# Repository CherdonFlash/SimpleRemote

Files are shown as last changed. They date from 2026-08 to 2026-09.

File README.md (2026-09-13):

# SimpleRemote

## 项目介绍

SimpleRemote 是基于 STM32F103C6T6A 设计的一款小型无线遥控器，集成双摇杆、四个按键、拨动开关、OLED 屏幕和锂电池充电电路。遥控器通过 NRF24L01 发送摇杆、按键、开关和电池电压数据，通过 CW2015CHBD 获取电池电量并显示在屏幕上。

尽量保持代码模块化，并为主要逻辑添加中文注释，方便理解和二次开发。屏幕界面由我结合 AI 辅助和手写绘图函数实现。

- Git项目仓库：[CherdonFlash/SimpleRemote](https://github.com/CherdonFlash/SimpleRemote)
- 联系 QQ：1228879785

## 项目图片

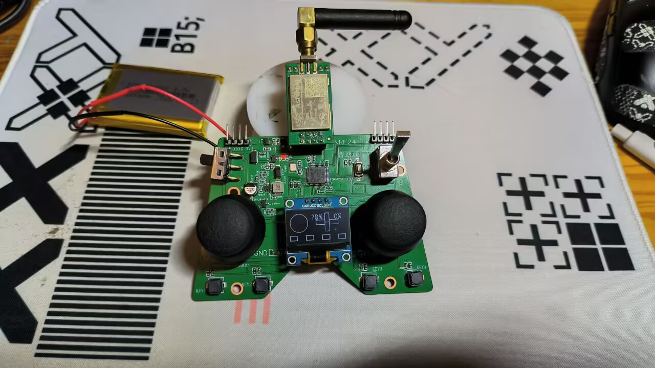
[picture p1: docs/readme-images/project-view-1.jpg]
项目图片 1


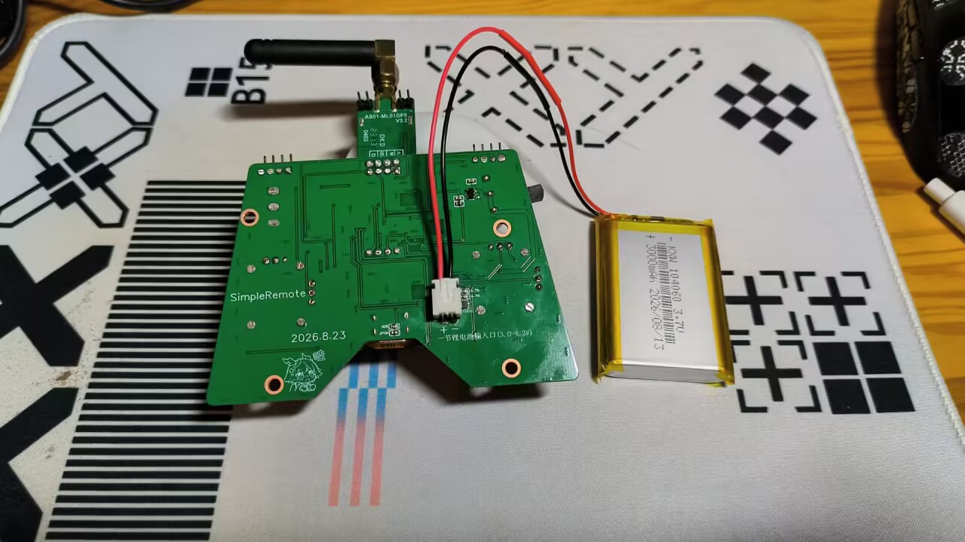
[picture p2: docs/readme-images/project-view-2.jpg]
项目图片 2


## 功能架构

```mermaid
flowchart TB
    subgraph IN["输入采集"]
        J1["双轴摇杆 ×2<br/>ADC1 + DMA（PA2/PA3/PA4/PB0）"]
        K1["按键 ×4<br/>TIM2 中断扫描（PB12～PB15）"]
        S1["拨动开关<br/>GPIO 读取（PA8）"]
    end

    subgraph BAT["电池与电量监测"]
        B0["1S 锂电池<br/>3000 mAh · 内置保护板"]
        B1["CW2015CHBD 电量计<br/>电池电压 · SOC<br/>软件 I2C（PB10/PB11）"]
        B0 --> B1
    end

    P1["STM32F103C6T6A · 72 MHz<br/>输入处理 · 数据组包 · 显示更新"]

    subgraph OUT["输出"]
        D1["0.96 英寸 OLED<br/>I2C1 + DMA（PB6/PB7）"]
        R1["NRF24L01 无线发送<br/>SPI1 · 32 字节数据帧"]
        U1["USART1 调试输出<br/>115200 · 8N1"]
    end

    J1 --> P1
    K1 --> P1
    S1 --> P1
    B1 --> P1
    P1 --> D1
    P1 --> R1
    P1 --> U1
    P1 -. 周期喂狗 .-> W["独立看门狗 IWDG"]
```

## 主要功能

| 模块 | 功能 | 主要源码 |
| --- | --- | --- |
| 双摇杆 | ADC1 四通道连续采样，DMA 循环搬运，映射为四路有符号控制量 | [mobile.c](mcu/Code/mobile.c) |
| 按键 | 四个按键周期扫描、消抖，非阻塞状态机识别单击、双击和长按 | [key.c](mcu/Code/key.c) |
| 拨动开关 | 读取开关档位，参与显示和无线组包 | [turn.c](mcu/Code/turn.c) |
| OLED | 128×64 帧缓冲绘图，硬件 I2C＋DMA 全屏刷新，显示摇杆、按键、开关和电量状态 | [app_display.c](mcu/Code/app_display.c)、[oled096.c](mcu/Code/oled096.c)、[iic.c](mcu/Code/iic.c) |
| 无线发送 | 硬件 SPI1 驱动 NRF24L01，发送 32 字节控制数据，启用自动应答和自动重发 | [nrf24.c](mcu/Code/nrf24.c) |
| 电量监测 | PB10/PB11 开漏 GPIO 模拟 I2C，每秒读取电池数据，更新屏幕电量百分比 | [cw2015.c](mcu/Code/cw2015.c)、[bat.c](mcu/Code/bat.c) |
| 串口 | USART1 输出初始化信息和发送数据；支持格式化输出，采用阻塞发送 | [uart.c](mcu/Code/uart.c) |
| 看门狗 | 主循环定期喂独立看门狗，异常时自动复位 | [main.c](mcu/User/main.c) |

### 无线数据帧

无线载荷固定为 32 字节，组包逻辑位于 [NRF_SendAll()](mcu/Code/nrf24.c)。

| 字节偏移（从 0 开始） | 内容 | 编码 |
| --- | --- | --- |
| 0 | 帧头 | `0x51` |
| 1～4 | 四路摇杆控制量 | 每路 `int8_t`，范围 −128～127，以 8 位补码传输 |
| 5 | 四个按键的按住状态 | bit0～bit3 对应按键 1～4，1 表示按住；bit4～bit7 为 0 |
| 6 | 拨动开关 | `turn_get()` 返回的 0/1 |
| 7～8 | 电池电压 | 单位 mV，7 为高字节，8 为低字节 |
| 9～30 | 预留 | 0 |
| 31 | 帧尾 | `0x15` |

按键字段使用消抖后的持续按住状态。无线芯片启用 2 字节 CRC，帧头和帧尾用于标识业务数据格式。

## 主控与主要元器件

主控采用 STM32F103C6T6A，Cortex-M3 内核，外部 8 MHz 晶振经 PLL 倍频至 72 MHz。程序采用裸机主循环，使用 STM32F10x 标准外设库 V3.5.0，Keil 工程按 32 KB Flash、10 KB RAM 配置。

STM32F103C6 具有一路硬件 I2C 和一路 SPI：OLED 使用 I2C1，无线模块使用 SPI1，电量计使用独立的软件 I2C。器件资料见 [ST 官方页面](https://www.st.com/en/microcontrollers-microprocessors/stm32f103c6.html)。

| 元器件 | 用途 |
| --- | --- |
| STM32F103C6T6A | 输入采集、显示和无线通信主控 |
| E01-ML01DP5 | 基于 NRF24L01+ 的 2.4 GHz PA 无线模块 |
| 0.96 英寸 OLED | 128×64 SSD1306 显示模组，四针 I2C 接口 |
| 3D161 摇杆 ×2 | 提供四路模拟控制量 |
| K2-1817UQ-C4SW-01 ×4 | 轻触按键输入 |
| CW2015CHBD | 单节锂电池电压与电量监测 |
| IP2312U | USB-C 输入的单节锂电池充电 |
| FP6291LR-G12 | 电池升压供电 |
| RT9013-33GB-MS ×2 | 分别产生主系统 3V3 和无线模块 NRF24_3V3 |
| 8 MHz 晶振 | MCU 外部高速时钟源 |

## 接口定义

| 功能 | STM32 引脚 |
| --- | --- |
| 摇杆 ADC | PA2、PA3、PA4、PB0 |
| 电量计软件 I2C | PB10/SCL、PB11/SDA |
| 按键 1～4 | PB12～PB15，外部上拉，低电平按下 |
| 拨动开关 | PA8 |
| OLED I2C1 | PB6/SCL、PB7/SDA |
| NRF24L01 SPI1 | PA5/SCK、PA6/MISO、PA7/MOSI |
| NRF24L01 控制 | PB8/CE、PB9/CSN、PA15/IRQ |
| USART1 | PA9/TX、PA10/RX，115200 baud、8N1 |

## 性能、功耗与续航

以下整理了我的电流测量记录、固件运行统计和理论估算。估算使用 3000 mAh 标称容量，并假设记录的电流为电池端整机平均电流；实际续航受电池容量、温度、老化和工作状态影响。

### 电池与功耗

| 项目 | 参数 / 数据 | 说明 |
| --- | --- | --- |
| 电池 | 1S 聚合物软包锂电池，3000 mAh | 内置保护板，支持 3 A 充电 |
| 关机静态电流 | **32.7 μA** | 实测整机关机电流 |
| 开机运行电流 | **54 mA** | 实测运行电流，随供电电压和工作状态变化 |
| 关机耗电量 | 约 0.785 mAh/天、23.54 mAh/30 天 | 按 32.7 μA 计算，不含自放电 |

### 无线、屏幕与按键

| 项目 | 参数 / 数据 | 说明 |
| --- | --- | --- |
| 无线射频中心频率 | **2.400 GHz** | RF_CH＝0 |
| 无线空中数据速率 | **2 Mbps** | 射频配置值 |
| SPI1 时钟 | **9 MHz** | 72 MHz 八分频 |
| OLED I2C 时钟 | **400 kHz** | 硬件 I2C1，已通过 60.104 s 软件稳定性测试 |
| OLED 完整刷新率 | **约 19.65 FPS** | 400 kHz、关闭逐包日志，60.104 s 完成 1181 帧 |
| 按键扫描周期 | **10 ms** | TIM2 定时扫描，100 Hz |
| 按键消抖响应时间 | **约 10～20 ms** | 从输入稳定到软件确认的代码推算，不含机械抖动和硬件 RC 延迟 |
| 长按判定时间 | **500 ms** | 按键状态机计时参数 |
| 双击等待窗口 | **400 ms** | 按键状态机计时参数 |
| 电量计采集周期 | **1000 ms** | 首次立即读取，之后每秒更新 |

OLED 刷新率统计于 2026-09-13：历史基线为 300 kHz 总线且保留逐包串口日志，约 14.09 FPS；本次关闭逐包日志并将 I2C 提升到 400 kHz，60.104 s 完成 1181 帧，约 19.65 FPS。该数值表示完整帧传输完成速率，会随主循环负载变化。详细测试结果见[固件优化与调试记录](mcu/固件优化与调试记录_2026-09-13.md)，测量脚本为 [Measure-Runtime.ps1](scripts/firmware/Measure-Runtime.ps1)。

### 充电与续航估算

| 项目 | 估算结果 | 计算依据 |
| --- | --- | --- |
| 充电电流设定 | **约 2.65 A** | IP2312U 的 ICHG 电阻为 51 kΩ，135000/51000≈2.647 A，属于名义设定值 |
| 标称容量÷设定充电电流 | 约 1.13 小时（68 分钟） | 3000 mAh÷2647 mA，仅为全程恒流假设下的容量换算 |
| 满电持续开机续航 | **约 55.6 小时（2.31 天）** | 3000 mAh÷54 mA |
| 满电关机、仅静态负载耗尽容量 | 约 3823 天（10.47 年） | 3000 mAh÷0.0327 mA，忽略自放电、老化及低压截止损失 |
| 每天开机 1 小时、关机 23 小时 | 约 54.8 天 | 每日耗电约 54＋0.0327×23＝54.75 mAh |

充电采用恒流/恒压过程，**68 分钟不是实际充满时间**；恒压收尾、输入限流和温度都会影响充电时长。**10.47 年也不是安全存放或补电周期**，不能用它判断电池何时严重过放。上述时间均为估算，不能代替完整充放电及长期存放测量。

充电参数依据[原理图网表](hardware/electronics/新版遥控器V1.1.tel)和[英集芯 IP2312U 数据手册，第 6～7 页](https://datasheet.lcsc.com/datasheet/pdf/846feb3b6ab45044a5c29188d4a683e3.pdf?productCode=C605432)。

## 选购与装配

我在选型时主要考虑成本、焊接难度和复现便利性。采购时请结合[电子设计资料](hardware/electronics/README.md)核对型号、封装和尺寸。

| 部件 | 注意事项 |
| --- | --- |
| MCU | 核对 STM32F103C6T6A 的完整型号和封装 |
| 摇杆 ×2 | 我选用 5 kΩ 电位器摇杆，左侧双轴不回中，右侧单轴不回中；安装时核对脚位、轴高及回中方向，旋转 90° 会交换相对外壳的控制轴方向 |
| OLED | 选择 128×64、SSD1306 兼容、适用 3.3 V 的 I2C 模组；H1 的 1～4 脚为 GND、VCC、SCL、SDA，同时核对排针高度和屏板尺寸 |
| 按键 / 拨动开关 | 核对封装、脚距和高度；拨动开关还需确认公共端与两档的连通关系 |
| 无线模块 | 核对 E01-ML01DP5 的 8 针定义、供电和外形，装好匹配的 2.4 GHz 天线再正常发射 |
| 电池 | 使用支持板级充电电流、带保护板的 1S 锂电池，焊接前核对正负极 |
| 电源芯片 | 小封装焊接前确认定位标记和 1 脚；检查去耦电容、焊接质量和工作温升 |
| 串口 | 使用 3.3 V 逻辑电平 USB 转串口，TX/RX 交叉并共地 |

无线模块使用独立的 RT9013 稳压供电。E01-ML01DP5 在 20 dBm 发射条件下的典型电流约为 130 mA，电源设计需考虑发射瞬态，不能只按整机平均电流选型，参见[亿佰特官方参数](https://www.ebyte.com/product/7.html)。

### 选购图片参考

下面是我选购时保存的截图，方便查看器件外观和规格。下单时仍需核对上表中的型号、封装和尺寸，截图价格仅供参考。

主控芯片：

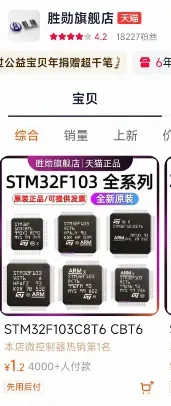
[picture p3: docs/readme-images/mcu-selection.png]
主控芯片选购参考


摇杆规格：装配需要两个摇杆，注意回中方式和安装方向。选用360度回中5K。（也可以按照你的方式来选不回中）

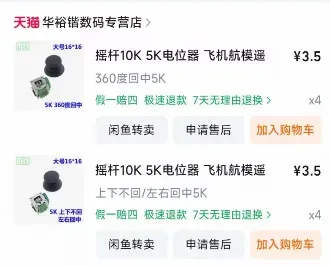
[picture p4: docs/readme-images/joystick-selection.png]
摇杆规格与选购参考


拨动开关：

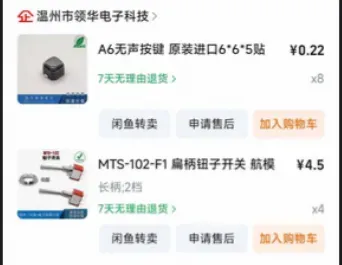
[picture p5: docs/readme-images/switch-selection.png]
拨动开关选购参考


无线模块：图片用于外观参考，采购型号和引脚定义按 E01-ML01DP5 核对。

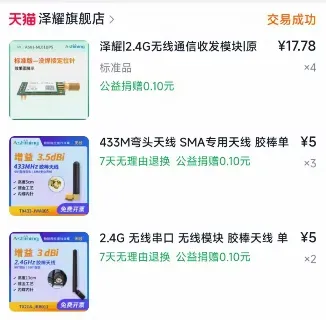
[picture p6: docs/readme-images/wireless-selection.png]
无线模块选购参考


电源配件：dcdc芯片可以在优信电子买。电池我买的3000mah，容量随意，但是注意尺寸。

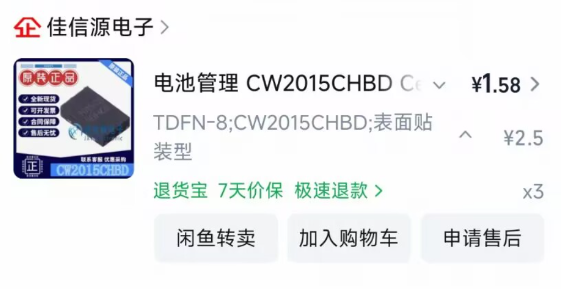
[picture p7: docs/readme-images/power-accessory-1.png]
电源配件参考 1


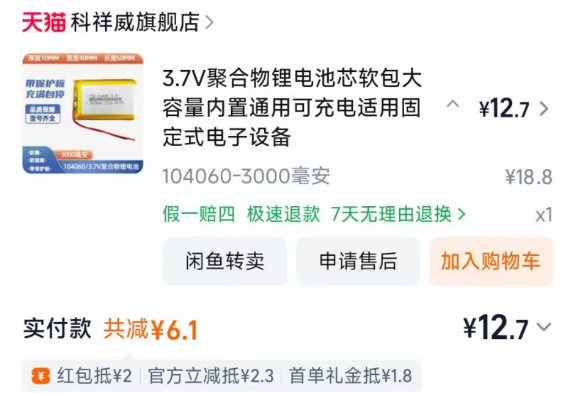
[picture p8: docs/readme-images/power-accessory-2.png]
电源配件参考 2


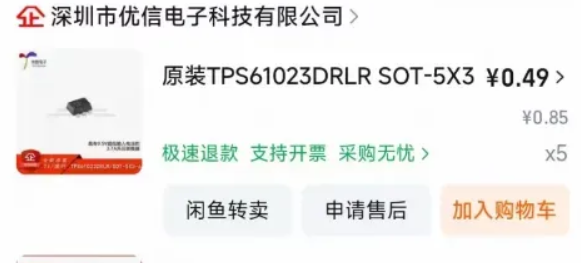
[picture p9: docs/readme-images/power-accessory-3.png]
电源配件参考 3


这些都是主要的元器件，剩下部分元器件不过多展开描述，对比PCB查看缺少的元器件购买就行，需要注意电容的耐压就行了。

电池接口是XH2.54-2P弯针类型，在优信电子有，对应的接口线也在优信电子有（不要忘记买接口线，可以焊接到电池两端）。

### 外壳

工程包含底壳、上壳、STEP/STL 文件和 SolidWorks 装配体，详见[机械设计说明](hardware/mechanical/README.md)。

- USB-C 在侧壁开口，方便插拔供电线。
- 左侧电源开关槽覆盖开、关两个拨动位置。
- OLED 从排针向 Type-C 方向延伸。
- 摇杆孔和 NRF24 开口按 PCB 三维模型定位。

打印或加工前，请结合装配实物核对孔位、器件高度、电池空间和插头插拔余量。

## 软件工作流程

我将初始化和主循环任务编排集中在 `main.c`，将屏幕布局放在 `app_display.c`，各外设驱动独立存放在 `mcu/Code/`。

上电完成时钟、看门狗和外设初始化后，主循环执行：

1. 处理 OLED DMA 完成状态、总线收尾和传输超时。
2. 每秒读取电量计，更新电池电压和电量百分比。
3. 更新四路摇杆控制量。
4. 组合摇杆、按键按住状态、拨动开关和电压，发送无线数据；逐包串口日志默认关闭，可通过编译开关临时启用。
5. 更新屏幕内容，显示异常时周期性尝试恢复。
6. 喂独立看门狗。

按键在 TIM2 中断中每 10 ms 扫描。`Key_IsPressed()` 获取消抖后的按住状态，`Key_TakeEvents()` 读取并清除单击、双击和长按事件；双击过程中会先产生单击事件，再产生双击事件。

OLED 全屏数据通过 DMA1 Channel 6 异步发送，主循环确认 BTF 和 STOP 收尾完成后释放传输状态。电量计无有效电量读数时显示“--%”，读取失败时保留最后有效电压。SOC 为芯片估算值，精度取决于电池曲线匹配与标定。

## 开发经验

### SPI 通信

调试 SPI 时，我主要结合数据手册和逻辑分析仪检查以下内容：

- 核对 CPOL/CPHA、位序、时钟频率、命令格式和片选有效电平。
- SPI 每发送一个字节，也同步接收一个字节；读取数据时需要继续发送 dummy 字节以提供时钟，具体数量按器件协议确定。
- NRF24 的命令阶段返回 STATUS，后续字节才是寄存器数据；单字节命令由 `NRF_Write_Cmd()` 处理。
- NRF24 的 CSN 低有效、空闲为高，CE 用于控制收发状态，两者不要混淆。
- 同时观察 CSN、SCK、MOSI 和 MISO 波形，按字节定位问题，并检查供电及上电时序。

### PB5 复用限制

我在调试中遇到过 SPI1 重映射到 PB3/PB4/PB5 后，与 OLED 的 I2C1 无法同时正常工作的情况。ST 的 [ES0348 勘误 §2.3.4](https://www.st.com/resource/en/errata_sheet/es0348-stm32f101x46-stm32f102x46-stm32f103x46-device-errata-stmicroelectronics.pdf)说明：当 I2C1 和 SPI1 时钟都开启、SPI1 重映射并作为主机、PB5 配置为复用输出时，SPI1 MOSI 会与 I2C1 SMBA 冲突，即使没有使用 SMBA。

因此，我使用 PA5/PA6/PA7 的默认 SPI1 引脚连接 NRF24，PB6/PB7 的 I2C1 连接 OLED，避开这一组合。

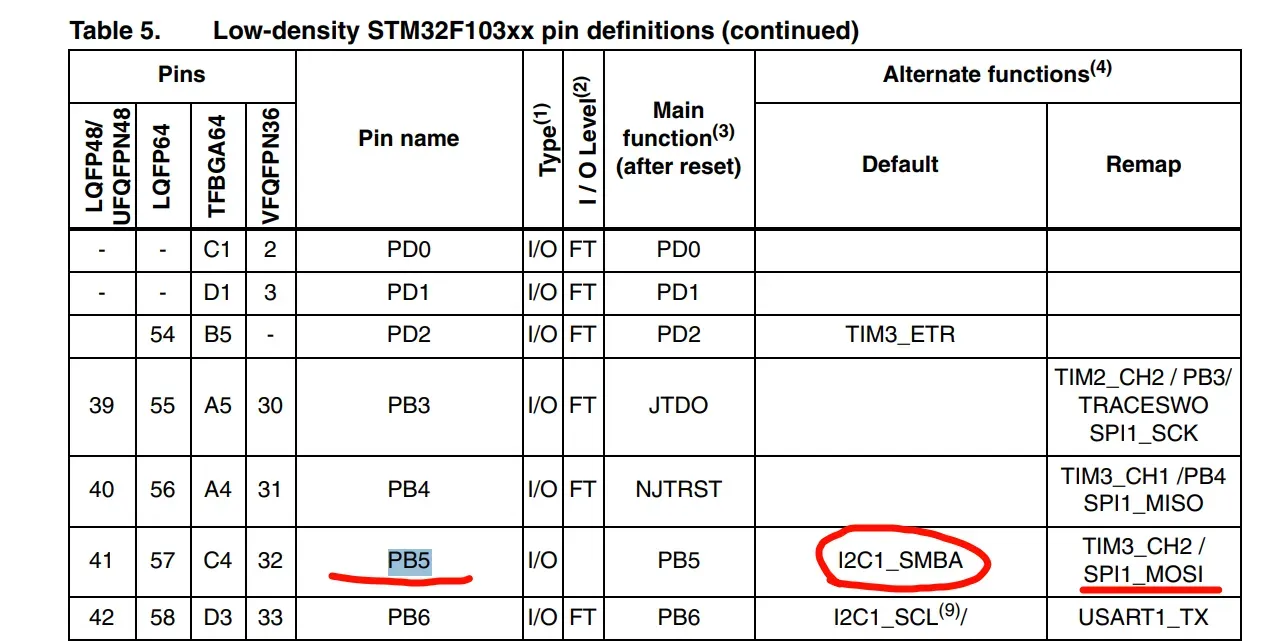
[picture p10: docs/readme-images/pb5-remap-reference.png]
PB5 引脚复用问题参考截图


## 目录结构

```text
SimpleRemote/
├─ README.md                 项目说明
├─ Git提交规范.md            中文约定式提交规范
├─ docs/
│  └─ readme-images/         README 项目图片及器件参考图片
├─ hardware/
│  ├─ electronics/           EDA 工程、原理图 PDF、网表和硬件说明
│  └─ mechanical/            外壳零件、交换文件和装配模型
├─ scripts/
│  ├─ firmware/              固件运行数据测量脚本
│  └─ mechanical/            SolidWorks 与 STEP 分析脚本
└─ mcu/
   ├─ Code/                  外设驱动与显示模块
   ├─ User/                  main.c 和中断服务函数
   ├─ Library/               STM32F10x 标准外设库
   ├─ start/                 CMSIS、系统时钟和启动文件
   └─ stm32f103c8t6.uvprojx  Keil 工程
```

## 开发与编译

- IDE：Keil MDK-ARM / μVision 5。
- 编译器：ARM Compiler 5，V5.06 update 7。
- 工程入口：[stm32f103c8t6.uvprojx](mcu/stm32f103c8t6.uvprojx)，目标器件配置为 STM32F103C6。
- 程序入口：[main.c](mcu/User/main.c)。
- 输出文件：`mcu/Objects/stm32f103c8t6.axf`、`stm32f103c8t6.hex`。
- 源码编码：UTF-8（无 BOM）。
- Git 提交遵循[Git提交规范.md](Git提交规范.md)，使用约定式提交格式和中文描述。

打开工程后，核对芯片配置、器件 Pack 和 ST-Link 下载设置，再编译下载。电子设计的工程文件、原理图和网表位于 [hardware/electronics](hardware/electronics/README.md)，机械文件位于 [hardware/mechanical](hardware/mechanical/README.md)。

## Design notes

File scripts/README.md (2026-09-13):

# 项目脚本

这里集中保存 SimpleRemote 设计和校核过程中由 AI 辅助生成的自动化脚本源码，避免脚本、编译产物与正式硬件文件混放。

## firmware

- `Measure-Runtime.ps1`：从当前AXF解析运行统计变量地址，使用ST-Link HotPlug读取两个时间窗口内的无线发送尝试/ACK/失败计数、OLED完整帧数及电量计成功读取数。不暂停CPU、不复位、不烧录。
- 运行示例：`./scripts/firmware/Measure-Runtime.ps1 -Seconds 30 -Windows 2 -Serial 0F381212A218303030303032`。
- 运行前必须烧录与当前AXF对应的固件；若本机工具路径不同，用`-Programmer`、`-FromElf`参数覆盖。输出为每个窗口一行JSON。
- 时间依据MCU的SysTick；分块读内存不是原子快照，边界处进行中的发送可能使尝试数和完成数差1，结果用于近似运行速率，不替代逻辑分析仪或端到端延迟测试。

## mechanical

- `BuildLatestEnclosure.cs`：按 2026-09-13 PCB 模型和 35.4×33.5mm OLED 构建外壳，通过 SolidWorks COM API 调用，无桌面操作。
- `BuildProductAssembly.cs`：生成产品装配体及 2400×1600 装配图，PCB 顶面位于 Z=17.6mm。
- `AnalyzeObjMesh.py`、`CheckMeshClearance.py`：分析 ZIP 中的 OBJ 网格，并以顶点和面重心采样检查穿壳情况；后者依赖 NumPy，不能替代实体干涉及实物试装。
- `AnalyzeNewPcbStep.py`：读取 STEP 实体关系并提取 PCB 与器件的机械包络。
- `BuildRemoteEnclosure.cs`：生成或修改遥控器上壳结构。
- `BuildShellAssembly.cs`、`BuildCorrectObjValidation.cs`：构建外壳及 PCB 对位校核装配体。
- `CheckAssemblyInterference.cs`、`CheckShellBodies.cs`、`SwInspector.cs`：检查装配干涉、实体状态和模型信息。
- `BuildNewPcbValidation.cs`、`BuildRemoteAssembly.cs`：早期基准模型的重建与校核源码，保留用于设计追溯。

Python 脚本可直接通过命令行运行。C# 脚本依赖本机 SolidWorks 2024 COM 接口及对应 Interop 程序集；生成的 EXE、DLL、PDB 和临时结果不纳入 Git。

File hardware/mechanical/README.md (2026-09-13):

# SimpleRemote 机械外壳

本目录保存 PCB 三维参考、上下壳零件、SolidWorks 装配体和产品装配图。外壳依据 `3D_PCB1_2026-09-13.zip` 中的 OBJ/MTL 模型设计，通过 SolidWorks 2024 COM API 构建和导出，没有使用鼠标、键盘或桌面截图操作。

## 产品装配图

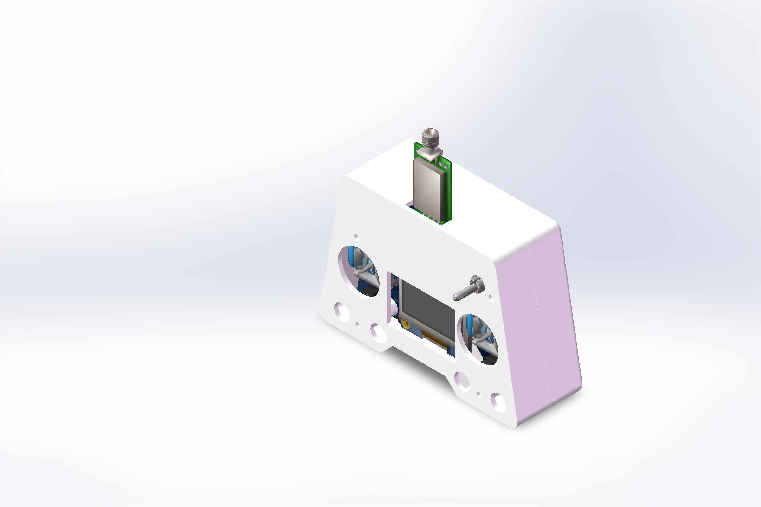
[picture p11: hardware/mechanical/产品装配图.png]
产品装配图


装配图由 SolidWorks 渲染 API 直接导出，分辨率为 2400 × 1600。图中包含上壳、底壳和 PCB 导出模型中的器件。

## 文件入口

| 文件 | 用途 |
| --- | --- |
| [遥控器产品装配体.SLDASM](遥控器产品装配体.SLDASM) | 产品装配入口，包含上下壳和 PCB |
| [遥控器新PCB校核装配体.SLDASM](遥控器新PCB校核装配体.SLDASM) | 同一套零件的对位校核装配体 |
| [遥控器外壳装配体.SLDASM](遥控器外壳装配体.SLDASM) | 仅包含上下壳 |
| `遥控器上壳.SLDPRT` / `.STEP` / `.STL` | 可编辑上壳、交换文件和打印网格 |
| `遥控器底壳.SLDPRT` / `.STEP` / `.STL` | 可编辑底壳、交换文件和打印网格 |
| [3D_PCB1_2026-09-13.zip](3D_PCB1_2026-09-13.zip) | PCB 三维导出原包 |
| [3D_PCB1_2026-09-13.SLDPRT](3D_PCB1_2026-09-13.SLDPRT) | OBJ 导入后的 SolidWorks 图形体 |
| [产品装配体_俯视图.png](产品装配体_俯视图.png) | 正面孔位与显示窗口 |
| [产品装配体_TypeC侧视图.png](产品装配体_TypeC侧视图.png) | USB 插拔凹口 |
| [产品装配体_电源开关侧视图.png](产品装配体_电源开关侧视图.png) | 电源开关侧槽 |
| [产品装配体_NRF24侧视图.png](产品装配体_NRF24侧视图.png) | 无线模块侧孔 |

打开装配体时，请保持这些零件位于同一目录。生成程序、分析程序和校核程序存放在 [scripts/mechanical](../../scripts/mechanical)。

## 设计参数

| 项目 | 参数与说明 |
| --- | --- |
| PCB 板框 | 约 98.263 × 66.650 mm，板厚约 1.600 mm |
| PCB 装配平移 | X＝−21.122147 mm，Y＝−41.820067 mm，Z＝17.600 mm |
| PCB 支承高度 | 底壳支柱顶面 Z＝16 mm，PCB 底面与支柱顶面对齐 |
| 上壳装配高度 | Z＝17.650 mm，接缝名义间隙约 0.05 mm |
| 外壳包络 | 约 102.264 × 70.650 × 34.850 mm，不含伸出的器件 |
| 上壳主体 | 高 17.2 mm，顶面和主要侧壁厚 2 mm，定位舌高 1.2 mm |
| OLED 模块 | 按确认的 35.4 × 33.5 mm 模型外形布置内腔，预留装配余量 |
| OLED 可视窗口 | 35.3 × 23.8 mm，按模型玻璃区域 34.5 × 23.0 mm 加每侧 0.4 mm；不是按整块屏板开通孔 |
| OLED 窗口位置 | 上壳 X＝12.155～47.455 mm，Y＝−29.185～−5.385 mm |
| 屏幕前伸罩 | 中部轮廓向 Type-C 方向前伸 8 mm，从上壳局部 Z＝7.5 mm 开始，下方保留 USB 插拔凹口 |
| USB-C 侧孔 | 总开口约 10.2 × 5.0 mm，跨上下壳接缝；底壳已补接口下半孔，俯视面不另开 USB 孔 |
| 电源开关侧槽 | 约 6.65 × 4.60 mm，覆盖拨柄及约 2.14 mm 两档行程；俯视面不开孔 |
| NRF24 侧孔 | 18.8 × 7.53 mm，按模块高度及 PCB 装配位置校准 |
| 摇杆孔 | 直径 21.5 mm；左右轴心分别为（−2.427，−13.356）和（59.041，−13.356）mm |
| 螺钉柱 | 柱位不变，底孔直径 2.5 mm；上壳两个后侧柱外径 5 mm，前侧柱外径 7 mm |
| 开关螺母避让 | 右后柱增加局部避让槽和通向侧壁的加强筋，减少螺母与柱体的空间冲突 |

PCB 原包 SHA-256：

```text
881F1B855C5F67EA5C6131750B5978CD39C77580C59CB4891DD092D3E48E4E53
```

## 校核记录

记录日期：2026-09-13。

| 检查 | 结果 |
| --- | --- |
| 上下壳原生文件打开 | 0 errors / 0 warnings |
| 上下壳实体数量 | 各 1 个实体 |
| SolidWorks 实体检查 | 两件的 `Body2.Check2()` 均返回 0 |
| 特征错误检查 | 未报告非零特征错误码 |
| 上下壳实体布尔相交 | 0 个相交体，体积 0 mm³，操作错误码 0 |
| PCB 网格穿壳采样 | 186,285 个顶点及三角面重心采样点，上下壳均为 0 个内部点；边界容差 0.02 mm |
| SLDPRT / STEP / STL 导出 | 保存成功，0 errors / 0 warnings |
| 产品装配体重新载入 | 0 errors，warning 32（NeedsRegen）；三个零件引用完整，API 强制重建返回 True，保存时 0 errors / 0 warnings |

装配体重新打开仍会报告需要重建的标志；这不是缺失零件警告。已执行强制重建并确认保存成功，但不将其记为“载入零警告”。

PCB 是 OBJ 图形体，因此不能把网格采样结果等同于完整实体干涉分析。采样也未覆盖器件运动全行程、实际线材、未建模的电池、摇杆帽和按键帽。正式加工前应做一次实物试装，重点确认：

- 摇杆摆动空间，以及按键帽高度和行程。
- Type-C 插头外壳是否能充分插入，下方线材是否受屏幕前伸罩影响。
- 电源开关两档是否能够拨到机械止点。
- 右后螺钉与拨杆开关螺母的余量，以及避让后的柱体强度。
- 电池固定、线材走线及屏幕固定方式。

修改前的目录文件已按 SHA-256 核对备份至 `backup_20260913_205722/`，便于恢复。备份不作为装配引用源。

## 重建与校核程序

- `BuildLatestEnclosure.cs`：生成上壳，并从底壳基准副本添加 Type-C 下半孔；参数为输出目录和未重复加工的底壳基准路径。
- `BuildProductAssembly.cs`：导入指定 OBJ，按装配坐标插入上下壳及 PCB，生成产品装配体和图片。
- `BuildShellAssembly.cs`：生成仅含上下壳的装配体。
- `AnalyzeObjMesh.py`：直接读取 PCB ZIP，统计连通网格包络。
- `CheckMeshClearance.py`：OBJ 采样点与上下壳 STL 的穿壳检查；要求 STL 保留 CAD 坐标、单位为 mm。
- `CheckShellBodies.cs`、`SwInspector.cs`：检查实体、特征、装配引用和上下壳相交情况。
- `RebuildAssembly.cs`：在正式文件路径强制重建并保存装配体，刷新载入时的重建标志。

C# 程序通过 SolidWorks COM API 调用，依赖 SolidWorks 2024 Interop 程序集；运行时不要关闭相关后台进程。脚本使用独立工作目录生成结果，确认校核结果后再替换正式文件。

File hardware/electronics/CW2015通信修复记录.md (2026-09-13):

# CW2015 通信修复记录

日期：2026-09-12。

## 原因与更正

板上主控为 STM32F103C6，ST-Link 识别设备 ID 0x412、32 KiB Flash。
该型号只有硬件 I2C1，没有硬件 I2C2。原驱动把 PB10/PB11 配为 AF_OD
并访问 I2C2，运行时这两脚读低，I2C2 寄存器始终读零，通信超时。
关闭原初始化后，两脚浮空输入时均为高。

原先“配置为 AF_OD 就能排除 MCU 拉低”“必定是芯片或焊接故障”的判断错误。
AF_OD 的输出受复用功能控制，不能仅凭 GPIO 输出锁存置高就认定管脚已释放。
本次使用普通开漏 GPIO 后同一块板立即读通，未要求更换芯片或修改连线。

来源：[ST STM32F103x4/x6 数据手册](https://www.st.com/resource/en/datasheet/cd00210843.pdf)。
原网名 IIC2_SCL / IIC2_SDA 仅是网络标签，不代表 F103C6 具备该外设。

## 修复实现

- PB10/SCL、PB11/SDA 使用 GPIO_Mode_Out_OD，速率配置 2 MHz。
- 写 1 释放总线，由原有 4.7 kΩ 电阻上拉；写 0 拉低，绝不推挽强拉高。
- 以 SysTick 实现至少 5 us 半周期，时钟低于或等于约 100 kHz，允许中断延长周期。
- 实现 START、重复 START、0xC4/0xC5 地址、ACK/NACK、STOP 和连续双字节读取。
- SCL 等待有 2 ms 超时；总线异常时最多补 9 个时钟并尝试 STOP，退出时释放双线。
- 上电读取 VERSION、MODE；必要时退出睡眠。每秒读取电压、SOC、RRT。
- 出错后下次周期重新初始化；保留最后有效业务读数，OLED 显示 --%。
- 取消 PB1 电压兜底调用：V1.1 已无对应分压，之前约 3.03 V 的 ADC 数值不能作为电池电压依据。
- 不写 BatteryInfo 电池曲线、不反复 quick start，避免把通信修复与 SOC 标定混为一谈。

## 实测验证

Keil 完整 Rebuild：0 error、0 warning。
Code 24526 B，RO-data 2394 B，RW-data 72 B，ZI-data 3864 B。
ST-Link 烧录及 Flash 校验成功，随后自动复位运行。

最终版本连续运行的快照：44 次尝试、44 次成功、0 次错误。
另执行 3 次 MCU 软件复位，各次复位后约 3 秒读到 4 次尝试、4 次成功、0 次错误。

| 项目 | 实测 |
| --- | --- |
| VERSION | 0x73 |
| 电压 | 3945～3946 mV |
| SOC | 整数70%，小数约0.6% |
| 驱动状态 | CW2015_OK（0） |
| GPIOB_CRH | 0x44446633，PB10/PB11普通开漏输出 |
| GPIOB_IDR | 0xFF38，PB10/PB11均为高 |
| 总线空闲诊断 | bus_levels=3 |
| RRT 原始字段 | 0x1FFF，本次不将其解释为可信剩余分钟数 |

诊断符号（最终本次 AXF，重新链接后应重新解析地址）：

- g_cw2015_data：0x200008D8，10 B，status 为偏移9的单字节枚举。
- g_cw2015_diag：0x200008E4，7个32位字段，依次为 attempts、successes、
  errors、last_success_ms、stage、last_register、bus_levels。

软件复位测试不会切断电池对 CW2015 的供电，因此完整断电再上电尚未在本次自动测试中验证。
通信已验证；实际容量/SOC精度仍需匹配电池曲线和实物放电测试确认。

## 主循环与屏幕显示接入（2026-09-12）

- 将首次数据采集统一放在主循环，进入循环立即读取，之后每1000 ms读取一次。
- 先采集再调用屏幕刷新，读取成功后同步更新 V_Bat 和 BAT_Percent。
- OLED 沿用原电量位置：数字 (42,5)，百分号 (68,5)，显示SOC整数部分；异常显示 --%。
- Keil重新编译：0错误、0警告，Code=24502 B，RO-data=2394 B，RW-data=72 B，ZI-data=3864 B。
- ST-Link烧录、校验成功。两次运行快照的成功计数从12增加至26，错误均为0；电压3945 mV，SOC约70.6%，BAT_Percent=70，显示缓冲区对应区域已有字符数据。
- 此验证确认数据持续采集及显示缓冲区更新，未通过相机核验实体屏幕画面。

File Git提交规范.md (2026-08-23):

# Git提交规范

本工程从本文件加入仓库后的下一次提交开始，统一采用[约定式提交（Conventional Commits 1.0.0）](https://www.conventionalcommits.org/zh-hans/v1.0.0/)格式。

除Git要求的固定关键字、代码标识符、器件型号和文件名外，提交标题、正文和脚注说明必须使用中文。所有参与者及自动化工具在本工程中创建Git提交时都必须遵守本规范。

## 1. 强制格式

```text
<类型>(<范围>)<可选的!>: <中文描述>

<可选的中文正文>

<可选的脚注>
```

最简示例：

```text
docs(readme): 更新V1.1硬件架构说明
```

完整示例：

```text
feat(mcu): 增加CW2015电量计驱动

通过I2C2读取电池电压、SOC和剩余运行时间，移除旧版PB1电池ADC采集逻辑。

Refs: #12
```

## 2. 标题规则

每个提交标题必须同时满足以下要求：

1. 必须使用本规范允许的英文小写类型。
2. 必须填写英文小写范围，并使用圆括号包围。
3. 类型/范围后必须使用英文冒号和一个空格，即`): `。
4. 冒号后的描述必须使用中文，器件型号、接口名和文件名可以保留原文。
5. 描述应直接说明本次提交完成了什么，不使用“修改一下”“更新文件”等模糊措辞。
6. 标题末尾不使用句号、感叹号等标点。
7. 标题建议控制在72个字符以内；确需补充的信息写入正文。
8. 一个提交只处理一个主要目的，不能把互不相关的修改放入同一提交。

## 3. 允许的类型

| 类型 | 用途 | 示例 |
| --- | --- | --- |
| `feat` | 增加用户可见功能、硬件功能或接口能力 | `feat(pcb): 增加CW2015电量计电路` |
| `fix` | 修复软件、原理图、PCB或结构设计缺陷 | `fix(power): 修正双电源切换控制网络` |
| `docs` | 只修改文档、注释或说明 | `docs(readme): 更新电量计架构图` |
| `refactor` | 重构实现，但不改变对外功能 | `refactor(mcu): 拆分电池管理模块` |
| `perf` | 提升性能、效率、功耗或资源占用 | `perf(power): 降低电池供电静态功耗` |
| `test` | 增加或修改测试、校核脚本 | `test(pcb): 增加网表一致性检查` |
| `build` | 修改编译系统、工具链或依赖 | `build(keil): 更新目标芯片编译配置` |
| `ci` | 修改持续集成或自动化检查 | `ci(git): 增加提交信息检查流程` |
| `chore` | 文件归档、版本整理等维护工作 | `chore(hardware): 归档新版遥控器V1.1设计文件` |
| `style` | 仅调整代码格式，不改变逻辑 | `style(mcu): 统一驱动代码缩进格式` |
| `revert` | 撤销以前的提交 | `revert(pcb): 撤销电源层布线调整` |

不得自行创造`hardware`、`update`、`modify`等新类型。硬件只是修改范围，应写成`feat(hardware)`、`fix(hardware)`或`chore(hardware)`。

## 4. 本工程允许的范围

| 范围 | 对应内容 |
| --- | --- |
| `mcu` | STM32固件通用修改 |
| `battery` | 电池检测、电量计及电池保护 |
| `power` | 充电、稳压、升压和双电源切换 |
| `radio` | NRF24L01无线通信 |
| `oled` | OLED显示及I2C1通信 |
| `pcb` | PCB布局、布线、层叠和封装 |
| `schematic` | 原理图和网表 |
| `hardware` | 同时涉及多个电子硬件模块的修改或归档 |
| `mechanical` | 外壳、装配体和SolidWorks模型 |
| `docs` | 多份通用文档 |
| `readme` | README说明 |
| `git` | Git配置、提交规范和仓库策略 |
| `build` | Keil工程、编译脚本和工具链 |
| `release` | 版本发布与发布说明 |

如果修改只涉及单一模块，应使用最具体的范围；同时涉及多个硬件模块时才使用`hardware`。需要新增范围时，应先修改本文件，再在后续提交中使用新范围。

## 5. 正文规则

简单修改可以省略正文。以下情况必须填写正文：

- 修改原因无法通过标题完整说明。
- 涉及硬件设计取舍、兼容性、功耗或安全影响。
- 修改了多个相互关联的文件。
- 需要记录验证方式、测试结果或已知限制。

标题和正文之间必须空一行。正文应优先说明“为什么修改”“如何修改”“验证结果”，避免简单重复标题。

示例：

```text
fix(power): 修正电池模式下Q2栅极下拉路径

USB移除后通过独立电阻为Q2栅极提供确定的低电平，避免依赖输入节点漏电流。
已核对原理图网表和PCB焊盘网络。
```

## 6. 破坏性变更

不兼容旧硬件、旧固件、通信协议或数据格式的修改必须标记为破坏性变更。

可以在范围后增加`!`：

```text
feat(radio)!: 调整无线数据帧中的电量字段
```

同时应在脚注中使用规范要求的固定关键字`BREAKING CHANGE:`，其说明使用中文：

```text
feat(radio)!: 调整无线数据帧中的电量字段

BREAKING CHANGE: 接收端必须同步升级，否则无法正确解析新的电量数据。
```

## 7. 问题关联和脚注

脚注与正文之间必须空一行。常用写法：

```text
Refs: #12
Closes: #15
Reviewed-by: 姓名
```

固定字段名可以使用英文，字段后的说明必须使用中文。

## 8. 本工程示例

```text
feat(battery): 增加CW2015电量计驱动
feat(pcb): 将电量计连接到PB10和PB11
fix(schematic): 修正电量计I2C网络标签
perf(power): 降低关机状态静态电流
docs(readme): 更新V1.1功能架构图
chore(hardware): 归档新版遥控器V1.1设计文件
test(mechanical): 增加外壳装配干涉检查
```

## 9. 禁止示例

```text
update files
修改代码
hardware: archive V1.1 design
feat: 增加电量计
feat(PCB): 增加电量计
docs(readme): update architecture
```

禁止原因依次为：缺少类型和范围、描述模糊、类型不在允许列表、缺少范围、范围不是小写、描述未使用中文。

## 10. 提交前检查

每次提交前必须依次完成：

1. 使用`git status --short`确认修改范围。
2. 使用`git diff --cached`核对暂存内容。
3. 确认没有密钥、账号、临时文件、编译缓存或无关修改。
4. 执行与修改相关的编译、测试、ERC、DRC或静态检查。
5. 按本规范编写中文提交描述。
6. 提交后检查`git log -1 --format=%B`。
7. 推送后确认本地提交与远端目标分支一致。

命令示例：

```powershell
git add README.md Git提交规范.md
git diff --cached
git commit -m "docs(git): 新增约定式提交规范"
git push origin main
```

## 11. 不符合规范时的处理

- 尚未推送：必须使用`git commit --amend`修正提交信息后再推送。
- 已经推送：不得擅自强制推送或改写公共历史；需要修正时必须先获得项目负责人明确同意。
- 合并提交、自动回滚提交等由Git平台生成的信息可以保留平台默认格式。
- 本规范生效前的历史提交不要求追溯修改。

## 12. 自动检查建议

当前首先以本文件作为强制流程规范。后续可以增加commit-msg Hook或CI，并使用commitlint的`@commitlint/config-conventional`规则自动拒绝不合规提交。若自动检查规则与本文件冲突，应以本文件中的项目专用类型、范围和中文描述要求为准，并同步修正规则配置。

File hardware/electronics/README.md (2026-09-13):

# 电子硬件设计

本目录保存嘉立创 EDA 专业版工程、网表、原理图导出文件及投板前复核记录。

## 当前版本

当前投板版本统一命名为“新版遥控器V1.1”：

| 文件 | 内容 | SHA-256 |
| --- | --- | --- |
| `新版遥控器V1.1.epro` | 完整嘉立创 EDA 专业版工程，包含原理图、PCB、符号库和封装库 | `44CB1FBB13764D67D35BCA7CC2060DD280721D79CFE264ADB2F2444457DBF1B1` |
| `新版遥控器V1.1.tel` | 与上述工程同批导出的原理图网表 | `BAECD971D408CB62C579648757DD8863955BCB2A413B844EEE14ACB702679753` |
| `新版遥控器V1.1.pdf` | 当前版本原理图PDF | `B7CC167E61C7E91ADB74890B6C117E297C9BC9D8F04B8979454F4EB4F684A61B` |
| `REVIEW_新版遥控器V1.1.md` | 本次静态复核结果、设计前提和投板检查项 | 见文件内容 |

下载目录中的原理图PDF、EPRO和网表导出时间分别为2026-08-23 15:23:34、15:25:15和15:25:22。归档后重新计算的哈希与源文件一致。目录内旧版EPRO、网表和PDF均已删除，电子设计导出文件只保留上述V1.1版本。

## 静态复核结果

- EPRO压缩工程结构完整，包含1张原理图和1块双层PCB。
- 工程包含91个器件位号、61个网络。
- 网表中的279项明确引脚—网络关系均能在PCB焊盘网络中找到，网络不一致数量为0。
- CW2015使用独立软件I2C（F103C6无硬件I2C2）：PB10/U23.21为SCL，PB11/U23.22为SDA。
- R57、R56分别将IIC2_SCL、IIC2_SDA通过4.7 kΩ上拉到3V3。
- 旧版PB1电池ADC及10 kΩ/10 kΩ分压已从当前原理图和PCB删除。
- CW2015外围与典型应用一致：CELL串470 Ω（R55），VDD串100 Ω（R54），两路各有1 µF电容。
- ALRT#当前不连接，软件每秒轮询读取。

以上是文件级静态检查，不能替代嘉立创 EDA 中实际执行ERC、DRC以及对最终Gerber的目视检查。

## 已确认的设计前提

- 项目不使用STM32的RTC后备电源功能，U23.1（MCU VBAT）按当前设计保持未连接；原始锂电池网络`VBAT`最高约4.2 V，不得接到该引脚。
- VDDA/VSSA滤波网络L6、L7是人工确认保留的设计。
- Q2在USB移除后通过`R17 → +5V公共节点 → R10 → R53`形成到GND的下拉路径，不是悬空栅极。
- 电池允许3 A充电，并且电池内部自带过充、过放、过流和短路保护板。
- 2026-09-12 已通过PB10/PB11软件I2C读取CW2015；已停止PB1电压兜底调用。参见[通信修复记录](CW2015通信修复记录.md)。

## 系统结构

```text
USB-C 5 V
   │
   ├─ IP2312U充电 ── 带保护板的1S锂电池 VBAT
   │                         │
   │                         ├─ CW2015电量计 ── 软件I2C/PB10/PB11
   │                         │
   │                         └─ SW13主开关 ── Q1/FP6291升压路径
   │                                                │
   └─ USB供电隔离路径 ───────────────────────────── VOUT
                                                    ├─ RT9013 U25 → 3V3
                                                    └─ RT9013 U26 → NRF24_3V3
```

## 主要器件

| 位号 | 型号/数值 | 功能 |
| --- | --- | --- |
| U23 | STM32F103C6T6A，LQFP-48 | 主控制器 |
| U2 | E01-ML01DP5 | NRF24L01+ 2.4 GHz PA无线模块 |
| U27 | CW2015CHBD，TDFN-8 | 单节锂电池电压、SOC和剩余时间估算 |
| U3 | IP2312U，ESOP-8 | 单节锂电池开关充电管理 |
| U1 | FP6291LR-G12，SOT-23-6 | 电池升压转换器 |
| U25 | RT9013-33GB-MS | 主系统3V3稳压 |
| U26 | RT9013-33GB-MS | NRF24独立3V3稳压 |
| SW6、SW7 | 3D161 | 双轴摇杆 |
| SW13 | SS12D06G5 | 电池回路主电源开关 |
| USB1 | XY-TYPEC-6PIN | 仅供电USB Type-C接口 |

## MCU信号对应

| 功能 | 网络 | MCU引脚 |
| --- | --- | --- |
| 左摇杆X/Y | L1、L2 | PA2、PA3 |
| 右摇杆X/Y | PA4、PB0 | PA4、PB0 |
| 按键1～4 | IO1～IO4 | PB12～PB15 |
| 功能开关 | PA8 | PA8 |
| OLED | IIC_SCL、IIC_SDA | PB6、PB7 / I2C1 |
| CW2015 | IIC2_SCL、IIC2_SDA | PB10、PB11 / 软件I2C |
| NRF SPI | PA5、MISO、MOSI | PA5、PA6、PA7 |
| NRF控制 | CE、CSN、IRQ | PB8、PB9、PA15 |
| 调试串口 | PA9、PA10 | USART1 |
| SWD | PA13、PA14 | SWDIO、SWCLK |

## 投板输出检查

生成Gerber和下单前仍应在嘉立创EDA内完成：

1. 重新铺铜后运行ERC和DRC，确认未连接网络及错误数量为0。
2. 核对U27的1脚方向、中央散热焊盘、阻焊开窗和钢网开窗。
3. 核对D1、D2、D3、Q1、Q2、LED、电解电容和Type-C接口方向。
4. 检查NRF24天线区域的铜皮、走线、外壳和电池净空。
5. 用Gerber查看器复核板框、钻孔、铜层、阻焊层、丝印层和钢网层。
6. 确认BOM中的电感、电源芯片、二极管和MOS管型号与实际采购料一致。

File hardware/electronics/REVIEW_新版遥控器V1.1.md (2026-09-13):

# 新版遥控器V1.1投板前复核记录

复核和归档日期：2026-08-23。

## 归档文件

| 文件 | 原始导出时间 | 大小 | SHA-256 |
| --- | --- | ---: | --- |
| `新版遥控器V1.1.epro` | 2026-08-23 15:25:15 | 350,153 B | `44CB1FBB13764D67D35BCA7CC2060DD280721D79CFE264ADB2F2444457DBF1B1` |
| `新版遥控器V1.1.tel` | 2026-08-23 15:25:22 | 4,997 B | `BAECD971D408CB62C579648757DD8863955BCB2A413B844EEE14ACB702679753` |
| `新版遥控器V1.1.pdf` | 2026-08-23 15:23:34 | 363,699 B | `B7CC167E61C7E91ADB74890B6C117E297C9BC9D8F04B8979454F4EB4F684A61B` |

三份文件从下载目录复制后统一改名，复制前后SHA-256一致。电子硬件目录中的旧版 `.epro`、`.epro2`、`.tel` 和 `.pdf` 文件已删除。

## 静态检查结果

- EPRO压缩包结构完整，包含`project.json`、原理图、PCB、符号库和封装库。
- 项目名称为“简易遥控器”，PCB名称为“简易版”。
- EPRO中的PCB包含91个器件位号和61个网络。
- 网表包含279项明确引脚连接，与PCB焊盘网络逐项比较，差异数量为0。
- 原理图PDF共1页，可以正常解析，并包含CW2015、IIC2_SCL和IIC2_SDA。
- CW2015连接PB10/PB11，SCL/SDA各有4.7 kΩ上拉。2026-09-12更正：F103C6不具备硬件I2C2，固件须使用软件I2C；原网络名IIC2_SCL/IIC2_SDA仅为标签。
- CW2015外围为CELL串470 Ω、VDD串100 Ω，两路各配置1 µF电容。
- PB1电池ADC连接已经从V1.1硬件中删除。
- Q2栅极通过R17、+5V公共节点、R10和R53形成到GND的下拉路径。

## 已确认的设计条件

- 不使用STM32的VBAT后备供电功能。
- VDDA/VSSA的L6、L7滤波方案保留。
- 电池支持3 A充电，并且内部带保护板。
- CW2015驱动及原PB1 ADC固件将在后续修改。

## 结论

在上述条件成立的前提下，未发现原理图、网表与PCB之间的网络同步阻断项，新版遥控器V1.1作为当前投板版本归档。

本记录属于导出文件静态复核，不能替代嘉立创EDA的ERC/DRC、最终Gerber检查、BOM/坐标核对及首板实测。

## 2026-09-12 实测补充

已修复将STM32F103C6误当作支持硬件I2C2的固件问题。保留原PCB走线，在PB10/PB11上使用普通开漏GPIO模拟I2C后，CW2015版本、电压、SOC均可读取。之前文件级网络一致性检查未识别MCU外设资源限制。详见[通信修复记录](CW2015通信修复记录.md)。

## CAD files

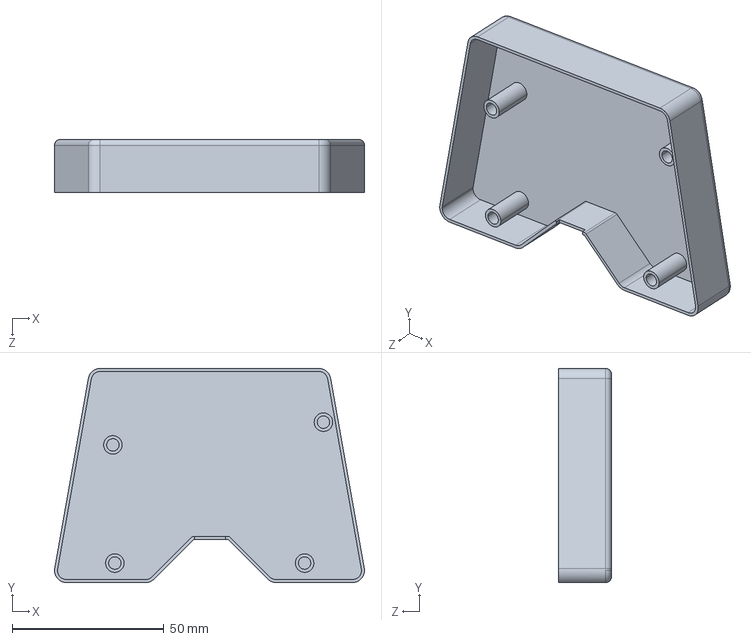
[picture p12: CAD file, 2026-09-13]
hardware/mechanical/遥控器底壳.STEP
102.3 x 70.6 x 17.6 mm

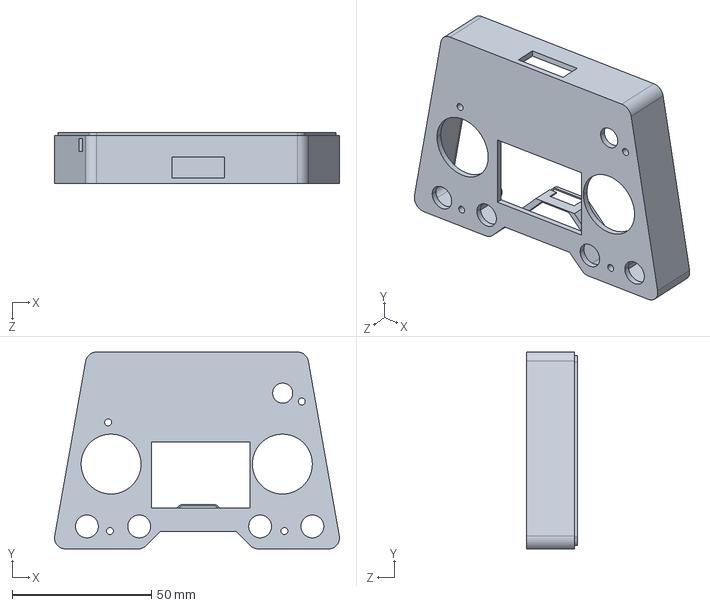
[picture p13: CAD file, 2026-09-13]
hardware/mechanical/遥控器上壳.STEP
102.3 x 70.6 x 18.4 mm

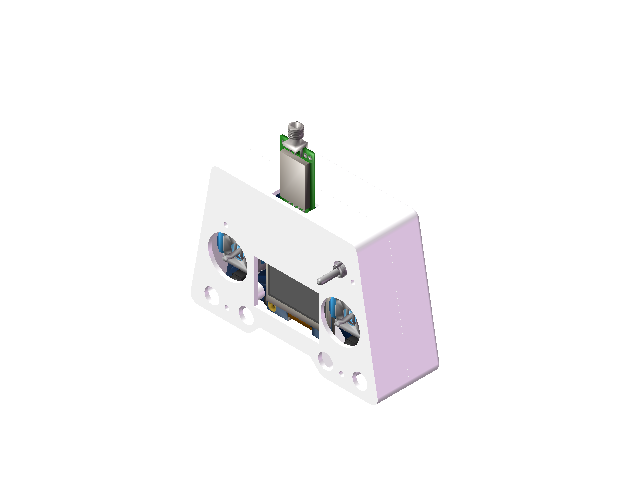
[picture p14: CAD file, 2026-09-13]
hardware/mechanical/遥控器新PCB校核装配体.SLDASM
遥控器底壳
遥控器上壳
3D_PCB1_2026-09-13

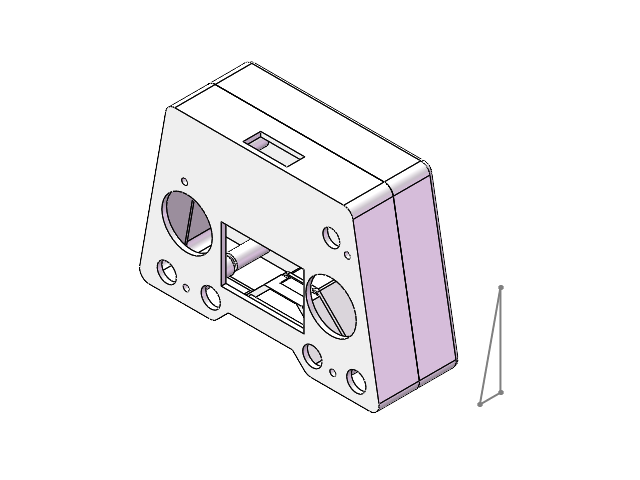
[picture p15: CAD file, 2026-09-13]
hardware/mechanical/遥控器外壳装配体.SLDASM
遥控器底壳
遥控器上壳

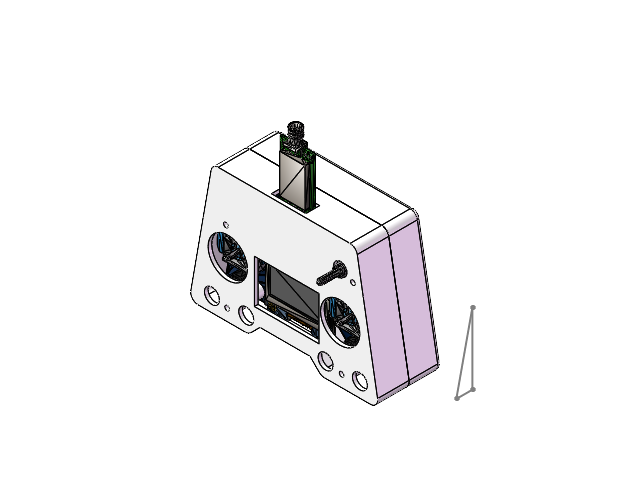
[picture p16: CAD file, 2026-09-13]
hardware/mechanical/遥控器产品装配体.SLDASM
遥控器底壳
遥控器上壳
3D_PCB1_2026-09-13

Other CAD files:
hardware/mechanical/3D_PCB1_2026-09-13.SLDPRT
hardware/mechanical/遥控器上壳.SLDPRT
hardware/mechanical/遥控器上壳.STL
hardware/mechanical/遥控器底壳.SLDPRT
hardware/mechanical/遥控器底壳.STL

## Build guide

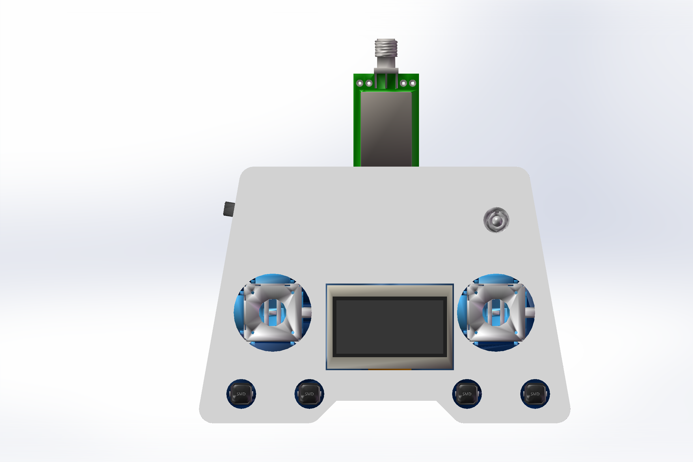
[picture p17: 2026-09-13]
hardware/mechanical/产品装配体_俯视图.png

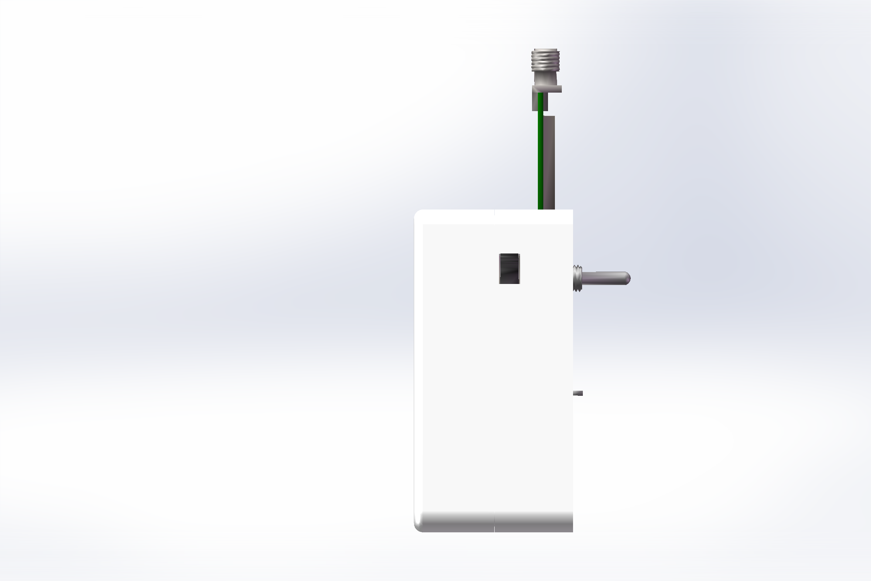
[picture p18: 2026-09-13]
hardware/mechanical/产品装配体_电源开关侧视图.png

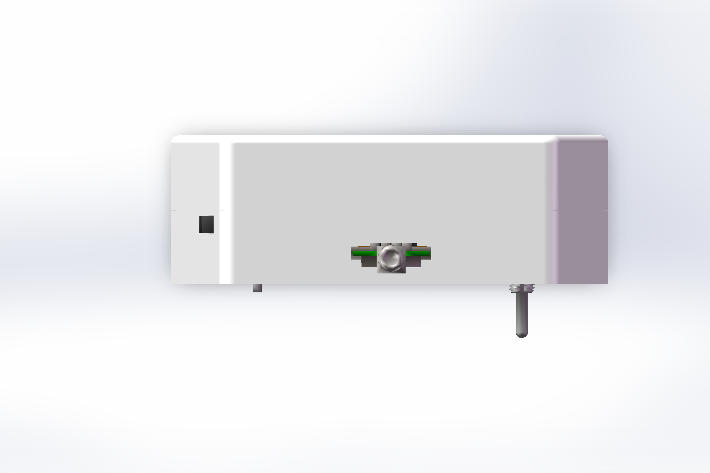
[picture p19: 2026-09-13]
hardware/mechanical/产品装配体_NRF24侧视图.png

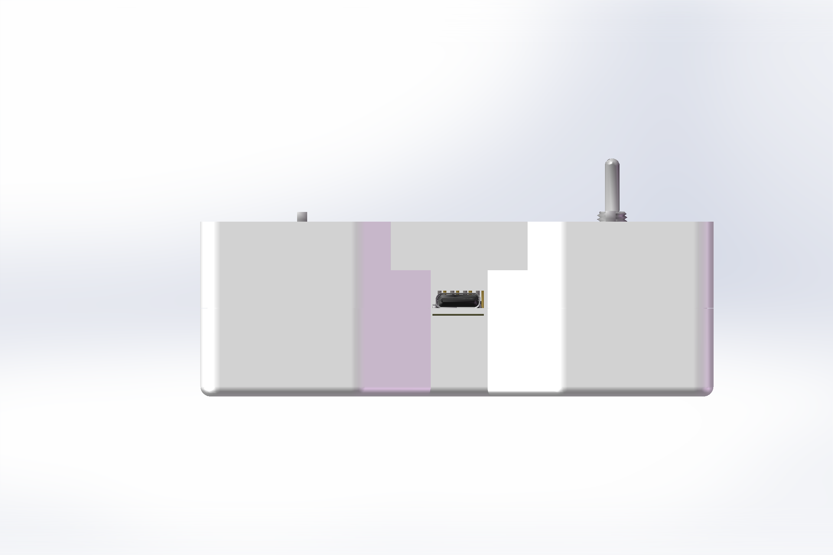
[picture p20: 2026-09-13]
hardware/mechanical/产品装配体_TypeC侧视图.png

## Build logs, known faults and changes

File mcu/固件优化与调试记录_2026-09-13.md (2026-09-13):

# 固件优化与调试记录

日期：2026-09-13。工程：SimpleRemote V1.1 / STM32F103C6。

## 修改范围

按用户选择，仅实施上次评审的1、2、4、6（SPI八分频），以及移除旧电池ADC和保留每秒电量采集。
优化阶段未关闭串口逐包日志，未改变无线包长度、地址、射频速率或自动重发配置，未新增摇杆滤波/校准；最终测试固件通过编译开关关闭逐包日志。

- `main.c`：分离初始化、每秒电量任务和看门狗配置；主循环独立更新摇杆后发送，屏幕故障不再冻结摇杆映射值。
- `app_display.c/.h`：独立管理原屏幕布局和显示恢复；电量位置与整数百分比格式不变。
- `iic.c/.h`：同步阶段每次等待上限5ms，OLED异步帧总超时100ms；处理NACK、总线错误及DMA传输错误。
  失败统一关闭DMA/I2C并释放引脚，恢复软件状态；显示任务每500ms最多尝试一次恢复。
  总线恢复最多发送9个时钟和STOP，然后重新初始化I2C与OLED。永久短路不会被软件修好，但重试有界。
- DMA中断只记录完成/错误；主循环确认BTF后发送STOP，确认STOP清除和总线空闲后再标记完成。
  时序参考[ST AN2824](https://www.st.com/resource/en/application_note/an2824-stm32f10xxx-ic-optimized-examples-stmicroelectronics.pdf)。
- OLED初始化和设置窗口命令改为连续命令事务，错误立即返回，不再忽略初始化失败。
- `key.c/.h`：TIM2 PSC=7199、ARR=99，72MHz定时器时钟对应10ms。按住状态独立进行按下/松开消抖。
  无线包四个按键位与屏幕方框都使用`Key_IsPressed()`，不再将单击/双击事件当作按住状态。
  增加`Key_TakeEvents()`原子读取并清除缓存事件位；同类事件未消费时合并，不是无限事件队列。
  保留先单击、后双击的原事件语义；事件暂不新增到无线包中。
- SPI1：72MHz/8=9MHz。仍使用原硬件SPI及现有发送流程。
- NRF24逐包串口日志改为编译开关`NRF_PACKET_LOG_ENABLE`，默认关闭；需要调试时显式改为1。
- OLED I2C测试配置改为400kHz；已完成几十秒故障观察和60秒刷新率测试，未出现I2C错误、恢复、卡死或看门狗复位，因此保留400kHz。若后续逻辑分析仪发现上升沿或电平裕量不足，再回退300kHz。
- ADC：扫描顺序仅PA2、PA3、PA4、PB0；DMA缓冲区为4个半字。删除BAT_ADC及BAT_Get旧分压估算。
  PB1仅保持未使用的模拟输入状态，不参与ADC扫描。
- CW2015：驱动不改，首次进入主循环立即采集，此后1000ms一次，失败自动重试。

`iic_dma_tx_done`等中断共享状态统一使用volatile声明。
旧通用I2C读取接口当前没有业务调用；保留了有界单字节寄存器读取实现，多字节接口按递增地址逐寄存器读取，不用于需要原子快照的电量计。

## 编译与烧录

- Keil ARM Compiler 5完整Rebuild：0错误、0警告。
- Code=24038 B，RO-data=2426 B，RW-data=96 B，ZI-data=3888 B。
- 最终HEX：`Objects/stm32f103c8t6.hex`，编程工具报告25.94KB。
- SHA256：`2F83FEAE210E6E9D9516094D34D6E1D4B7264CF5668A864EFD1D3F59D453B622`。
- 烧录前识别到Device ID=0x412、32KB Flash、Cortex-M3，确认不是上一块F4板。
- ST-Link SN：`0F381212A218303030303032`，目标参考电压3.20V。
- 写入、Flash校验成功，随后复位运行。未提交Git、未推送。

## 实机观察

本次通过ST-Link读取的寄存器：

| 项目 | 读值与解释 |
| --- | --- |
| RCC_CFGR | 0x001DC40A，系统72MHz，APB2不分频、APB1二分频 |
| SPI1_CR1 | 0x00000354，BR=010，八分频 |
| TIM2_PSC / ARR | 0x1C1F / 0x63，即7199 / 99，周期10ms |
| ADC1_SQR1 | 0x00300000，序列长度4 |
| ADC1_SQR3 | 0x00041062，通道顺序2、3、4、8 |
| DMA1_Channel1 | 内存指向0x2000003C，循环采集四个半字 |
| CW2015 | VERSION=0x73，电压3996mV，SOC约79.3%，显示整数79% |

首次运行快照：CW2015从38次成功增长到94次成功，错误为0；OLED成功帧数持续增长。
在9MHz SPI下程序已通过原NRF五字节寄存器写读自检并进入主循环；这不等于已经验证远端接收成功率。

### 软件错误注入的观察与限制

在首轮固件运行时尝试通过ST-Link把RAM中DMA错误标志置1。工具返回8位写入失败，
因此不能把该命令本身标记为可靠写入成功；随后读回观察到I2C错误数由0变1、恢复数由0变1，
成功刷新继续增长且当前错误状态恢复为0，与一次瞬态错误恢复相符。
这一观察不能替代实体断屏、拉低总线及DMA中断丢失的完整故障测试。

之后软件复位，清零诊断计数：观察到CW2015 42/42成功、OLED完成590帧，均0错误。
最终保留PB1模拟输入的版本再次完整编译、烧录和校验；最终运行快照见下方补充。

最终版本约67秒运行快照：CW2015 67次尝试、67次成功、0错误；OLED已启动948帧、完成947帧（1帧进行中），错误0、恢复0。系统节拍0x00010733持续运行，SPI/TIM2/ADC配置再次读回与上表一致。

## 调试变量

以下地址只适用于本次AXF，重新编译后必须重新解析符号：

- `systick_ms`：0x20000038。
- `adc_values[4]`：0x2000003C；四路映射值：0x20000044～0x20000047。
- `g_iic_diag`：0x20000464，五个uint32字段依次为started、completed、errors、recoveries、last_error。
- `g_cw2015_data`：0x20000908；`g_cw2015_diag`：0x20000914。

## 尚需实物确认

- 拨动两个摇杆、按住并松开四个按键，确认屏幕与接收端动作符合预期。
- 实体OLED断开/重新连接后的恢复、缺屏冷启动、SDA/SCL持续拉低测试。
- 接收端在线时的9MHz SPI长期收包率、无线丢包和实际控制延迟。
- 未测量本次修改后的整机电流，不承诺续航改善幅度。

## 固定配置与README性能表补充

同日后续按用户要求删除main.c中的三个宏：CW2015_I2C_ENABLE、BATTERY_UPDATE_MS、WATCHDOG_TIMEOUT_MS。
CW2015固定初始化并每1000ms更新，看门狗固定1000ms；寄存器地址等驱动常量不属于本次删除范围。

NRF增加内存诊断计数，不增加串口输出、不改变发送策略；分别记录尝试、ACK成功、重发耗尽、其他错误及发包间隔。
运行测量脚本：`scripts/firmware/Measure-Runtime.ps1`，只读HotPlug，不暂停CPU。

### 本次最终固件（取代上文优化阶段HEX）

- 编译：0错误、0警告；Code=24122、RO-data=2426、RW-data=96、ZI-data=3928 B。
- HEX SHA256：`A4C527D0D650BC4554C054F37D7B9BA89380728A91E9620D73A1379114D24080`。
- 已重新烧录、Flash校验通过，ST-Link目标仍为0x412/32KB。
- 统计地址：systick_ms=0x20000038、g_iic_diag=0x20000464、g_nrf_diag=0x20000908、g_cw2015_diag=0x2000093C。
  原CW2015数据地址已移动，不可继续使用上文旧地址；脚本从AXF自动解析。

### 原始运行窗口

保留串口逐包日志、OLED正常连接、无ACK应答；温度和供电路径未完整测量。两次快照读取跨度为3～4ms。

| 窗口 | MCU时间差/s | 发送尝试 | ACK成功 | MAX_RT完成 | 其他发送错误 | OLED完成帧 | OLED错误/恢复 | 电量读取成功/错误 |
| --- | --- | --- | --- | --- | --- | --- | --- | --- |
| 1 | 30.0940 | 1696 | 0 | 1696 | 0 | 424 | 0/0 | 30/0 |
| 2 | 30.1085 | 1696 | 0 | 1697 | 0 | 424 | 0/0 | 30/0 |

分块快照时有发送正在进行，因此窗口2的发送完成计数与尝试计数相差1，不按逐包原子配对解释。
总观察时间60.2025s：3392次发送尝试，约56.343Hz；848次完整屏幕刷新，约14.086fps。
本次启动以来发包间隔最小16ms、最大25ms；这是观察值，不能当作异常工况下的硬实时保证。
启动读回RF_CH=0、RF_SETUP=0x0F，对应中心频率2400MHz、空中速率2Mbps。

主README已加入用户电流数据（关机32.7μA、开机54mA）、3000mAh电池、上述速率、按键软件延迟推算、充电和续航表。
充电电流按归档网表R3=51kΩ与IP2312U手册计算名义约2.65A；容量除以设定电流约1.13h，不标为实际充满时间。
关机10.47年和开机55.6小时均为忽略自放电/容量折减等因素的理论值，未做完整充放电或多年存放实测。

### 400kHz + 关闭逐包日志最终测试（2026-09-13）

- 配置：OLED I2C1=400kHz；`NRF_PACKET_LOG_ENABLE=0`，关闭每个无线包的串口打印；无线参数和发送策略未改变。
- 40秒故障观察分为两个约20秒窗口：OLED分别完成395帧和394帧，刷新率19.644/19.612FPS；两窗口I2C错误/恢复均为0，电量计读取20/20成功，看门狗未复位。
- 60秒稳定性测试：运行60.104s，OLED完成1181帧，实测完整刷新率 **19.649FPS（约19.65FPS）**；I2C错误=0、恢复=0，电量计读取60/60成功。
- 发送尝试约5902次、约98.20Hz；测试时接收端未应答，因此ACK=0、MAX_RT为正常重试结果，不代表OLED或I2C故障。窗口边界可能有1个正在进行的发送，不按快照做逐包原子配对。
- 本次测试通过ST-Link只读运行计数和诊断变量，未使用逻辑分析仪直接测量SDA/SCL模拟波形；因此已验证软件长时间稳定性，但最终量产前仍建议抽测400kHz上升时间、电平和噪声裕量。
- 结论：当前版本保留400kHz，不回退300kHz；若后续实测波形不满足I2C Fast-mode规范，再按记录回退。

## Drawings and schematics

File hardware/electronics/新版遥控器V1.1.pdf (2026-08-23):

# NRF24L01

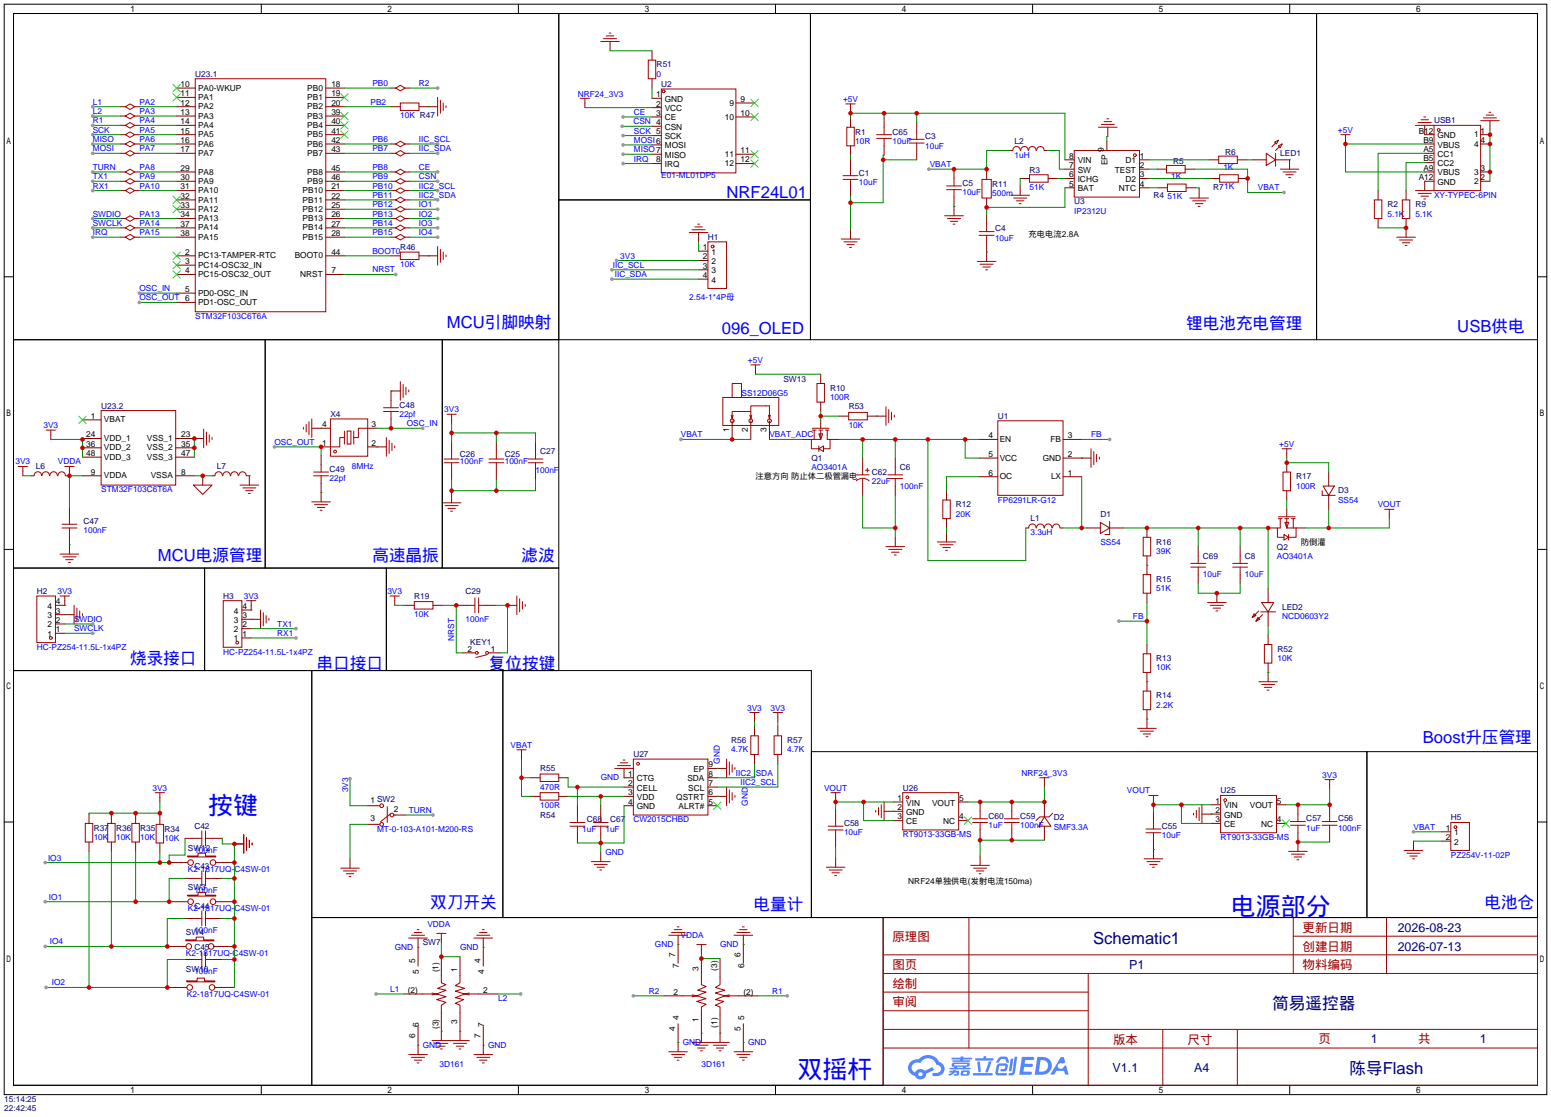
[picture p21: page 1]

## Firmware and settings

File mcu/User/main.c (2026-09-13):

#include "stm32f10x.h"
#include "delay.h"
#include "key.h"
#include "uart.h"
#include "turn.h"
#include "mobile.h"
#include "nrf24.h"
#include "bat.h"
#include "cw2015.h"
#include "iic.h"
#include "app_display.h"

/* 普通遥控器原开源项目：
 * https://github.com/mcforyous/MB_Control
 * http://oshwhub.com/foryous/ordinary-remote-control-mbcontro
 */

static uint32_t battery_tick;
static void App_Init(void);
static void Battery_Task(void);
static void Watchdog_Init(uint16_t timeout_ms);

int main(void)
{
    App_Init();

    while (1) {
        I2C1_Service();       /* OLED异步DMA收尾、总线错误与超时检查 */
        Battery_Task();       /* 首次立即读取，以后每秒读取一次CW2015 */
        mobile_data();        /* 每轮独立更新摇杆；屏幕故障不冻结控制量 */
        NRF_SendAll();        /* 保留原32字节协议、重发配置和串口日志 */
        App_DisplayTask();    /* 仅显示最新状态；缺屏时低频尝试恢复 */
        IWDG_ReloadCounter();
    }
}

static void App_Init(void)
{
    while (SystemClock_HSE_72MHz() == 0);
    SysTick_Init();
    Watchdog_Init(1000U);     /* 固定1秒看门狗 */

    USART1_Init(115200);
    Key_Init_All();
    turn_init();
    mobile_init();           /* V1.1只采集四路摇杆，不再采集PB1电池电压 */
    CW2015_Init();            /* F103C6无I2C2，使用PB10/PB11软件开漏I2C */
    App_DisplayInit();        /* 初始化失败允许继续运行，主循环负责重连 */
    nrf24_init();

    /* 无符号时间差支持GetTick回绕，首次进入主循环立即采集。 */
    battery_tick = GetTick() - 1000U;
    UART1_Printf("Init success!\n");
}

static void Battery_Task(void)
{
    uint32_t now = GetTick();
    if (now - battery_tick < 1000U) return; /* 固定每秒读取一次 */
    battery_tick = now;

    if (CW2015_Update() == CW2015_OK) {
        V_Bat = (float)g_cw2015_data.voltage_mv / 1000.0f;
        BAT_Percent = g_cw2015_data.soc_percent;
    }
    /* 失败保留最后有效业务值，屏幕显示--%，驱动下次自动重试。 */
}

static void Watchdog_Init(uint16_t timeout_ms)
{
    /* LSI按约40kHz估算，32分频后每计数0.8ms；避免浮点计算。 */
    uint32_t reload = (uint32_t)timeout_ms * 5U / 4U;
    if (reload > 4095U) reload = 4095U;
    IWDG_WriteAccessCmd(IWDG_WriteAccess_Enable);
    IWDG_SetPrescaler(IWDG_Prescaler_32);
    IWDG_SetReload((uint16_t)reload);
    IWDG_ReloadCounter();
    IWDG_Enable();
}

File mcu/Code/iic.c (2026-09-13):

#include "iic.h"
#include "oled096.h"

#define OLED_ADDR          0x78U
#define OLED_I2C_CLOCK_HZ  400000U /* 先测试400kHz；波形不稳时回退300kHz */
#define IIC_WAIT_MS        5U
#define IIC_FRAME_MS       100U
#define IIC_SCL            GPIO_Pin_6
#define IIC_SDA            GPIO_Pin_7
#define IIC_LINES          (IIC_SCL | IIC_SDA)
#define IIC_ERROR_BITS     (I2C_SR1_BERR | I2C_SR1_ARLO | I2C_SR1_AF | I2C_SR1_OVR)

extern uint8_t OLED_GRAM[8][128];
static uint8_t dma_buffer[1025];
static volatile uint8_t dma_phase; /* 0空闲、1搬运、2等待BTF、3等待STOP */
static volatile uint8_t dma_failed;
static uint8_t bus_fault;
static uint32_t dma_started_ms;
volatile uint8_t i2c_dma_tx_done = 1;
volatile IIC_Diagnostics g_iic_diag = {0};

static void IIC_ConfigPins(GPIOMode_TypeDef mode)
{
    GPIO_InitTypeDef gpio;
    GPIOB->BSRR = IIC_LINES;
    gpio.GPIO_Pin = IIC_LINES;
    gpio.GPIO_Speed = GPIO_Speed_2MHz;
    gpio.GPIO_Mode = mode;
    GPIO_Init(GPIOB, &gpio);
}

void I2C1_Init(void)
{
    I2C_InitTypeDef i2c;
    NVIC_InitTypeDef nvic;
    RCC_APB2PeriphClockCmd(RCC_APB2Periph_GPIOB | RCC_APB2Periph_AFIO, ENABLE);
    RCC_APB1PeriphClockCmd(RCC_APB1Periph_I2C1, ENABLE);
    RCC_AHBPeriphClockCmd(RCC_AHBPeriph_DMA1, ENABLE);
    GPIO_PinRemapConfig(GPIO_Remap_I2C1, DISABLE);
    DMA_Cmd(DMA1_Channel6, DISABLE);
    DMA_ClearFlag(DMA1_FLAG_GL6);
    I2C_DeInit(I2C1);
    IIC_ConfigPins(GPIO_Mode_AF_OD);
    I2C_StructInit(&i2c);
    i2c.I2C_ClockSpeed = OLED_I2C_CLOCK_HZ;
    I2C_Init(I2C1, &i2c);
    I2C_Cmd(I2C1, ENABLE);

    nvic.NVIC_IRQChannel = DMA1_Channel6_IRQn;
    nvic.NVIC_IRQChannelPreemptionPriority = 1;
    nvic.NVIC_IRQChannelSubPriority = 1;
    nvic.NVIC_IRQChannelCmd = ENABLE;
    NVIC_Init(&nvic);
    dma_phase = 0;
    dma_failed = 0;
    bus_fault = 0;
    i2c_dma_tx_done = 1;
}

/* 所有失败统一收尾；这里不循环重试，避免缺屏拖住遥控主循环。 */
static IIC_Status IIC_Abort(IIC_Status reason)
{
    DMA_ITConfig(DMA1_Channel6, DMA_IT_TC | DMA_IT_TE, DISABLE);
    DMA_Cmd(DMA1_Channel6, DISABLE);
    I2C_DMACmd(I2C1, DISABLE);
    DMA_ClearFlag(DMA1_FLAG_GL6);
    if (I2C1->SR2 & I2C_SR2_MSL) I2C_GenerateSTOP(I2C1, ENABLE);
    I2C_Cmd(I2C1, DISABLE);
    IIC_ConfigPins(GPIO_Mode_Out_OD); /* 释放双线，恢复留给低频重连任务 */
    dma_phase = 0;
    dma_failed = 0;
    bus_fault = 1;
    i2c_dma_tx_done = 1;
    ++g_iic_diag.errors;
    g_iic_diag.last_error = reason;
    return reason;
}

static IIC_Status IIC_WaitFlag(uint32_t flag, FlagStatus wanted)
{
    uint32_t start = GetTick();
    while (I2C_GetFlagStatus(I2C1, flag) != wanted) {
        if (I2C1->SR1 & IIC_ERROR_BITS) return IIC_BUS_ERROR;
        if (GetTick() - start >= IIC_WAIT_MS) return IIC_TIMEOUT;
    }
    return (I2C1->SR1 & IIC_ERROR_BITS) ? IIC_BUS_ERROR : IIC_OK;
}

static IIC_Status IIC_WaitStop(void)
{
    uint32_t start = GetTick();
    while ((I2C1->CR1 & I2C_CR1_STOP) || (I2C1->SR2 & I2C_SR2_BUSY)) {
        if (I2C1->SR1 & IIC_ERROR_BITS) return IIC_BUS_ERROR;
        if (GetTick() - start >= IIC_WAIT_MS) return IIC_TIMEOUT;
    }
    return IIC_OK;
}

static void IIC_ClearAddr(void)
{
    volatile uint32_t unused = I2C1->SR1;
    unused = I2C1->SR2;
    (void)unused;
}

/* 地址阶段保留 ADDR 标志，接收单字节时需要先关ACK再清ADDR。 */
static IIC_Status IIC_Address(uint8_t address, uint8_t direction)
{
    IIC_Status status;
    I2C_GenerateSTART(I2C1, ENABLE);
    status = IIC_WaitFlag(I2C_FLAG_SB, SET);
    if (status != IIC_OK) return status;
    I2C_Send7bitAddress(I2C1, address, direction);
    return IIC_WaitFlag(I2C_FLAG_ADDR, SET);
}

static IIC_Status IIC_BeginWrite(uint8_t address)
{
    IIC_Status status;
    if (bus_fault) return IIC_BUS_ERROR;
    if (!i2c_dma_tx_done) return IIC_BUSY;
    status = IIC_WaitStop();
    if (status == IIC_OK) status = IIC_Address(address, I2C_Direction_Transmitter);
    if (status == IIC_OK) IIC_ClearAddr();
    else IIC_Abort(status);
    return status;
}

IIC_Status IIC_WriteMulti(uint8_t address, uint8_t reg, const uint8_t *data, uint16_t len)
{
    uint16_t i;
    IIC_Status status;
    if (data == NULL || len == 0) return IIC_ARGUMENT;
    status = IIC_BeginWrite(address);
    if (status != IIC_OK) return status;
    I2C_SendData(I2C1, reg);
    status = IIC_WaitFlag(I2C_FLAG_BTF, SET);
    for (i = 0; i < len && status == IIC_OK; ++i) {
        I2C_SendData(I2C1, data[i]);
        status = IIC_WaitFlag(I2C_FLAG_BTF, SET);
    }
    if (status != IIC_OK) return IIC_Abort(status);
    I2C_GenerateSTOP(I2C1, ENABLE);
    status = IIC_WaitStop();
    return status == IIC_OK ? status : IIC_Abort(status);
}

IIC_Status IIC_WriteReg(uint8_t address, uint8_t reg, uint8_t value)
{
    return IIC_WriteMulti(address, reg, &value, 1);
}

IIC_Status I2C1_DMA_Write(uint8_t address, uint8_t reg, uint8_t *data, uint16_t len)
{
    return IIC_WriteMulti(address, reg, data, len);
}

/* 旧通用读取接口保留：逐寄存器单字节事务，遵守F1单字节接收ACK/ADDR顺序。
 * 当前OLED不用这些接口，CW2015使用独立的软件I2C驱动。 */
IIC_Status IIC_ReadMulti(uint8_t address, uint8_t reg, uint8_t *buf, uint8_t len)
{
    uint8_t i;
    uint32_t primask;
    IIC_Status status;
    if (buf == NULL || len == 0) return IIC_ARGUMENT;
    for (i = 0; i < len; ++i) {
        status = IIC_BeginWrite(address);
        if (status != IIC_OK) return status;
        I2C_SendData(I2C1, (uint8_t)(reg + i));
        status = IIC_WaitFlag(I2C_FLAG_BTF, SET);
        if (status == IIC_OK) status = IIC_Address(address, I2C_Direction_Receiver);
        if (status != IIC_OK) return IIC_Abort(status);
        primask = __get_PRIMASK();
        __disable_irq();
        I2C_AcknowledgeConfig(I2C1, DISABLE);
        IIC_ClearAddr();
        I2C_GenerateSTOP(I2C1, ENABLE);
        __set_PRIMASK(primask);
        status = IIC_WaitFlag(I2C_FLAG_RXNE, SET);
        if (status != IIC_OK) return IIC_Abort(status);
        buf[i] = I2C_ReceiveData(I2C1);
        status = IIC_WaitStop();
        I2C_AcknowledgeConfig(I2C1, ENABLE);
        if (status != IIC_OK) return IIC_Abort(status);
    }
    return IIC_OK;
}

uint8_t IIC_ReadReg(uint8_t address, uint8_t reg)
{
    uint8_t value = 0;
    (void)IIC_ReadMulti(address, reg, &value, 1);
    return value; /* 新调用应使用带状态返回的 ReadMulti，避免把失败当作零值。 */
}
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

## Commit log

2026-08-13 docs(readme): 初始化工程说明文档
2026-08-13 feat(release): 导入遥控器V1.0完整工程
    [遥控器上壳.SLDPRT, 遥控器上壳.STEP, 遥控器上壳.STL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]
2026-08-16 feat(release): 更新遥控器V1.0工程
2026-08-16 docs(readme): 增加功能架构图
2026-08-23 feat(hardware): 归档新版遥控器V1.1设计
2026-08-23 docs(git): 新增约定式提交规范
2026-09-13 chore(release): 整理并提交遥控器V1.1工程
    汇总最新PCB、外壳模型、固件优化、电量计驱动、README图片和分析脚本。
    固件已通过Keil编译（0错误、0警告），并完成ST-Link烧录校验。
    OLED使用400kHz I2C，关闭逐包日志后，60.104秒稳定刷新率约19.65FPS，I2C错误和恢复均为0。
    [3D_PCB1_2026-09-13.SLDPRT, 遥控器上壳.SLDPRT, 遥控器上壳.STEP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]
